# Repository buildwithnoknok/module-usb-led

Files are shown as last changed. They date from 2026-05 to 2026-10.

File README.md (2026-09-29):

# noknok LEDs

A USB-controlled ring of 8 WS2812b RGB LEDs for the noknok ecosystem. The Raspberry Pi
Pico drives it as a **USB host**; it can also be driven directly from a PC.

## Features
- 8× WS2812b RGB LEDs (ring)
- CH32V203G6U6 microcontroller, USB 1.1 (CDC) device
- USB-C power + data; 2× Qwiic / STEMMA QT compatible I2C pass-through connectors
- **Unique per-unit USB serial** derived from the chip UID — so the Conductor can tell
  identical modules apart and map them to roles (the USB counterpart of the I2C UID)
- Rich control: per-LED colour/brightness/timed-off in one command, plus 6 built-in
  animations (rainbow, breathe, theatre chase, colour wipe, twinkle, sundown)

## Status
- **Firmware: v1.8.2 — complete** (see [firmware/readme.md](firmware/readme.md) for the
  full command protocol, flashing instructions, and version history)
- Hardware: v1.0

## How it's controlled

### From a Raspberry Pi Pico (USB host) — the noknok Conductor
The Pico hosts the module over PIO-USB (D+ → GP16, D− → GP17, behind a **powered** hub
such as the DataHub). The `NoknokLEDs` driver lives in
[`brain-Pico/software/noknok_usb.py`](https://github.com/buildwithnoknok/brain-Pico/tree/main/software)
and is discovered by the Conductor:

```python
from noknok import Conductor

c = Conductor()
c.enumerate_usb()          # brings up the USB host port, finds all LED modules
# (use c.enumerate_all() for a product that mixes I2C + USB modules)

leds = c.leds[0]                                  # or c.by_uid("<serial>"), or c.role["lamp"]
leds.set_all(255, 0, 0)                           # all red
leds.set_pixel(3, 0, 255, 0)                      # LED 3 green
leds.set_brightness(128)                          # global brightness
leds.set_led(0xFF, 0, 0, 255, brightness=200, duration_ms=1000)  # all blue 1 s, then off
leds.play_preset(leds.PRESET_RAINBOW, speed=40)  # non-blocking animation on the module
leds.play_preset(leds.PRESET_SUNDOWN, speed=30, r=0, g=0, b=255)  # 30 min fade to off, blue
leds.off()
```

Each module carries a unique serial, so multiple LED modules on one hub are addressed
individually. See **[Ecosystem → enumeration.md](https://github.com/buildwithnoknok/Ecosystem/blob/main/software/enumeration.md)**
(USB Module Discovery & Identity) and **[roles.md](https://github.com/buildwithnoknok/Ecosystem/blob/main/software/roles.md)**
(role assignment — this is an *output* module, assigned by cue-and-confirm).

### From a PC
PowerShell / Python helpers in [`tools/`](tools) (`noknok_leds.ps1`, `noknok_leds_pc.py`)
auto-detect the module and expose the same commands.

## Repository Structure
- `/hardware` — KiCad files, schematics, 3D models
- `/firmware` — source (`src/`), built binaries (`bin/`), and the firmware change record (`readme.md`)
- `/tools` — PC control scripts

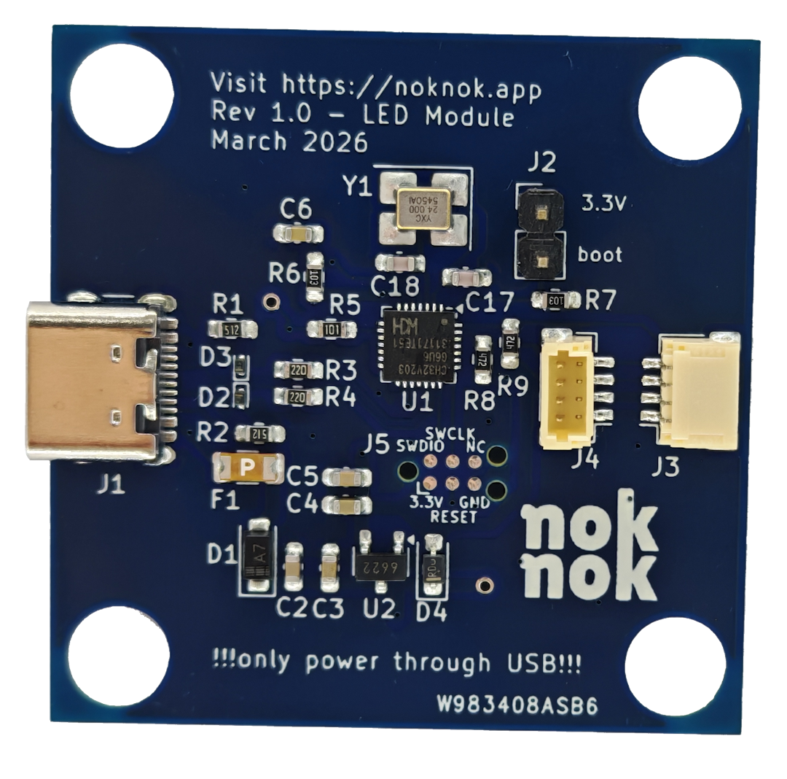
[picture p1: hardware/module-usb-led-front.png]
USB LED Module

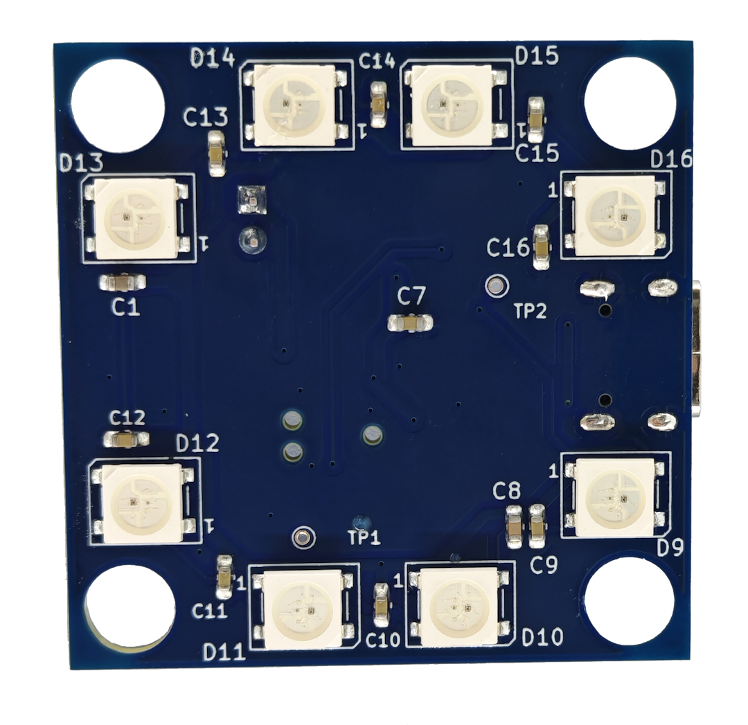
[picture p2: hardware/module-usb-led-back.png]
USB LED Module


---

## Trademarks

**noknok** is a registered trademark in Switzerland (Swissreg 1300007033).

Qwiic is a registered trademark of SparkFun Electronics, Inc. STEMMA QT is a
trademark of Adafruit Industries, LLC. Both are named here only to state
connector compatibility - noknok is not affiliated with, endorsed by, or
sponsored by either company.

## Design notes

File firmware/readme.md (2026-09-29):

# Firmware — noknok LEDs

Firmware for the noknok LEDs module (CH32V203G6U6 — USB, 8× WS2812b RGB).

- Source: `src/` (built with [ch32fun](https://github.com/cnlohr/ch32fun); `Makefile` uses `extralibs/usbd.c`)
- Binaries: `bin/noknok_leds.bin` and `bin/noknok_leds.hex` — current release
- USB identity: VID `0x1209` / PID `0x4E4E` (app) / PID `0x4E42` (bootloader). Appears as a CDC serial device ("noknok LEDs"). Each unit has a **unique serial number** derived from its chip UID (v1.6+).

Firmware is licensed MIT (see `../LICENSE-firmware`). Toolchain and protocol follow the
[noknok Ecosystem guidelines](https://github.com/buildwithnoknok/Ecosystem).

## Flashing (USB bootloader — no programmer needed)
1. Fit the **BOOT0 jumper**, plug into USB-C, power-cycle → the chip enters the WCH USB bootloader.
2. In **WCHISPTool**: select chip **CH32V203 (G6U6)**, load **`bin/noknok_leds.bin`**, click Download. Leave "Enable RRP" **unchecked**.
3. Remove the BOOT0 jumper and power-cycle.

A brief **dim-white boot flash (~0.3 s)** means the firmware is running; a **"noknok LEDs" COM port** then appears.
A *constant* solid-white means the firmware is **not** running (old/failed flash or bootloader mode) — re-flash.

> You can also flash `bin/noknok_leds.hex` the same way, or via SWD with a WCH-Link-E (`make flash`).

## Controlling the module
- From a PC: PowerShell / Python helpers in [`../tools/`](../tools) (`noknok_leds.ps1`, `noknok_leds_pc.py`).
- From a Raspberry Pi Pico (USB host): the `NoknokLEDs` class in the brain-Pico `noknok.py` (`usb.core`, raw bulk to EP `0x02`).

**Command protocol** (raw bytes, host → module):

| Bytes | Action |
|---|---|
| `0x00` | all LEDs off |
| `0x01 R G B` | set all 8 LEDs |
| `0x02 i R G B` | set LED `i` (0–7) |
| `0x03 B` | global brightness 0–255 |
| `0x04 [24 bytes]` | set all 8 LEDs: 8 × (R G B) |
| `0x05` | explicit show |
| `0x10 i R G B BR dLo dHi` | **SET_LED** — LED `i` (`0xFF` = all), colour, brightness, duration ms little-endian (0 = hold) |
| `0x20 preset speed R G B` | **PLAY_PRESET** 1–6 (rainbow / breathe / theatre-chase / colour-wipe / twinkle / **sundown**); `speed` = ms per step (0 = default) — **EXCEPT preset 6 (sundown), where `speed` means MINUTES instead (0 = default 30)**; `R G B` = base colour |
| `0xF0` | identity query → module replies `0x4E 0x4E 0x04` |
| `0xB1` | version query → replies `[PROTOCOL, MAJOR, MINOR, PATCH]` |

---

## Firmware Change Record

### v1.8.2 — lossless USB receive (current) — released 2026-09-29
- **Bug fix: commands could be lost or misread when sent back-to-back.** ch32fun `usbd.c`'s
  printf receive path (`FUNCONF_USE_USBPRINTF`) keeps a 64-byte buffer and throws away the
  OLDEST bytes when another USB packet arrives before the main loop has read it. The parser
  then desynced and leftover colour bytes ran as commands — a `0x00` byte means "all off",
  so the ring could go dark or show wrong colours. Found on the LEDs 16x bench.
- **Fix:** `FUNCONF_USE_USBPRINTF 0` (+ `FUNCONF_NULL_PRINTF 1`); the firmware implements the
  CDC callbacks itself with a 256-byte ring filled in the USB interrupt. When less than one
  packet (64 B) of room is left the USB interrupt is masked, so the endpoint answers NAK and
  the host simply retries — true flow control, no byte can be dropped. The main loop drains
  the ring, unmasks, then parses.
- Test: `tools/stress_leds8.py` (hundreds of back-to-back `0x04` frames, then compare the ring
  with the printed expected frame).
- No protocol or behaviour change otherwise. Flash 6360 B (26 %), RAM 1256 B.

### v1.8.1 — sundown preset — released 2026-07-02
- **New preset 6 = SUNDOWN.** `0x20 6 minutes R G B` plays a **one-shot** fade from full
  brightness to off in the caller-supplied colour, over `minutes` minutes (not the usual
  `speed`-as-ms/step — see below). Unlike presets 1–5, which loop forever until the next
  command, SUNDOWN runs once and stops itself (LEDs off) at the end instead of repeating.
  Intended for a bedtime/wind-down light (e.g. blue, 30 min).
- **Easing is CONCAVE (quadratic ease-out), not linear:** brightness follows
  `(1 - elapsed/total)²`, so it dims fast at the start and slows to a crawl near the end
  (e.g. at the halfway point in time, brightness is at 25%, not 50%). Computed in Q10
  fixed-point integer math — no FPU on this MCU, same approach as the rest of the firmware.
- **`speed` field is repurposed for this preset only:** every other preset's `speed` byte
  means "ms per animation step", which can't encode a useful multi-minute total duration in
  one byte. For preset 6 only, `speed` means **minutes** (1–255; 0 defaults to 30). This is a
  deliberate, documented exception — not a silent redefinition of the field ecosystem-wide.
- Flash usage 6328 B (26% of 24 KB app region), RAM 1060 B. No other behavioural changes
  from v1.8.0 (see v1.8.0 below for the OTA/bootloader-hosted architecture change).

### v1.8.0 — OTA-capable, bootloader-hosted — released 2026-06-23
- App relinked at `0x2000` (`app.ld`) to run under the noknok USB bootloader
  (`module-USB-bootloader`), with the top 16 B of RAM reserved as the handoff cell.
- `0xB0` ENTER_BOOTLOADER: writes the handoff magic + resets; the bootloader catches it and
  stays in USB flashing mode. Updates now flash over USB via `usb_flash.ps1` / the Pico's
  `UsbModuleFlasher` — no BOOT0 jumper needed after the bootloader's one-time flash.

### v1.6 — unique serial + rich LED control & presets — released 2026-06-18
- **Unique USB serial number.** `iSerialNumber` is now built at boot from the CH32V203's 96-bit hardware chip UID (ESIG at `0x1FFFF7E8`) as 24 hex characters, so every physical module enumerates with a **distinct serial**. This is the USB counterpart of the I2C hardware UID — it lets the Conductor tell identical modules apart and map them to roles. (Previously all modules shared the hardcoded serial `"007"`.)
- **`0x10` SET_LED — full per-LED control in one command:** `0x10 i R G B brightness durLo durHi`. `i` = LED index (`0xFF` = all); `duration` is 16-bit ms (little-endian; `0` = hold indefinitely, otherwise the LED(s) auto-off after the duration). Non-blocking.
- **`0x20` PLAY_PRESET — 5 built-in non-blocking animations** that run on the module (fire-and-forget, mirroring the buzzer's preset tunes): `1` rainbow rotate, `2` breathe, `3` theatre chase, `4` colour wipe, `5` twinkle. `0x20 preset speed R G B` — `speed` = ms per animation step (`0` = default 40 ms); `R G B` = base colour (ignored by rainbow). Any immediate command (`0x00`–`0x05`, `0x10`) cancels a running animation.
- Added a **TIM3 free-running 1 ms timebase** for durations and animation stepping.
- Flash usage 6052 B (18% of 32 KB), RAM 1056 B.

### v1.5 — adds firmware version query — released 2026-06-17
- **`0xB1` GET_VERSION command** (noknok ecosystem standard, command range 0xB0–0xBF). The module replies with 4 bytes: `[PROTOCOL_VERSION, FW_MAJOR, FW_MINOR, FW_PATCH]` = `0x01, 1, 5, 0`. Lets the host (Pico or PC) read which firmware a module is running — needed by the OTA update flow. Matches the I2C modules' `0xB1` convention.
- No other behavioural changes from v1.4.

### v1.4 — first working release — released 2026-06-04
- **USB stack switched from USBFS (fsusb) to USBD (FSDEV).** On this board the USBFS controller's D+ pull-up is not host-visible, so it never enumerated; the USBD/FSDEV controller (pull-up via `EXTEN_USBD_PU_EN`, the same path the WCH bootloader uses) enumerates reliably as a USB CDC device.
- **Manual clock bring-up: HSE 24 MHz × 2 = 48 MHz** (crystal-accurate 48 MHz USB clock). ch32fun's automatic CH32V203 clock setup does not work for this part (no flash wait-states above 24 MHz; it disables HSI mid-switch), so the firmware boots on the internal HSI and switches to the crystal + PLL itself.
- **Behaviour:** dim-white boot flash on power-up, then enumerates as "noknok LEDs" (VID `0x1209` / PID `0x4E4E`). LED commands are sent as raw bytes over the CDC data endpoint.
- Driveable from a PC (`../tools/`) or from a Pico acting as USB host (`usb.core`).

### v1.0 – v1.3 — bring-up (superseded, non-functional)
- Early builds used the USBFS (fsusb) stack and ch32fun's default 144 MHz clock. They did not run / did not enumerate due to the CH32V203 clock issues described under v1.4. Superseded.

### Abandoned experiment — full CDC line-coding (not released, no version assigned)
- An attempt (between v1.4 and v1.5) to add full CDC line-coding so standard host serial APIs (e.g. .NET `SerialPort.Open`) could open the port. Caused Windows "Code 10 — device cannot start"; root cause not isolated, so it was dropped. (PC tools instead open the port via a raw handle / pyserial, which works.)

## Known limitations
- The minimal CDC implementation does not fully answer line-coding requests, so .NET `SerialPort.Open()` is fussy. Use the provided PowerShell/Python tools (raw handle / pyserial), or `usb.core` raw bulk on the Pico.
- USB VID/PID are pid.codes **prototype** values (`0x1209` / `0x4E4E`) — assign production IDs before release.

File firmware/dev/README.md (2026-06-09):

# ch32fun dev patches (CH32V203)

Optional patches to cnlohr/ch32fun `ch32fun.c` that fix the automatic clock setup
for CH32V203 (flash wait-states at >24 MHz; HSE-enable preserving the active HSI).

NOT required by the shipped LED firmware (noknok_leds.c does its own manual HSE/PLL
bring-up). Kept for reference if anyone wants ch32fun's auto-clock to work on V203.
See the LED debug history in the Sam agent notes for full context.

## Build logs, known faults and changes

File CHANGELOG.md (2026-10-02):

# Changelog - noknok LEDs (8x) module firmware

Newest first. One entry per version bump, written in the same commit as the bump. Format:
`## <version> - <date>` then `- DEV-xx - what changed and why. Breaking: yes/no.`
Convention: Confluence "Development Conventions" (SD space, page 120160257).

## Baseline - 2026-10-02

- Changelog starts here. Current: usb_leds firmware 1.8.2 (released 2026-09-29). Earlier history: git log and the README.

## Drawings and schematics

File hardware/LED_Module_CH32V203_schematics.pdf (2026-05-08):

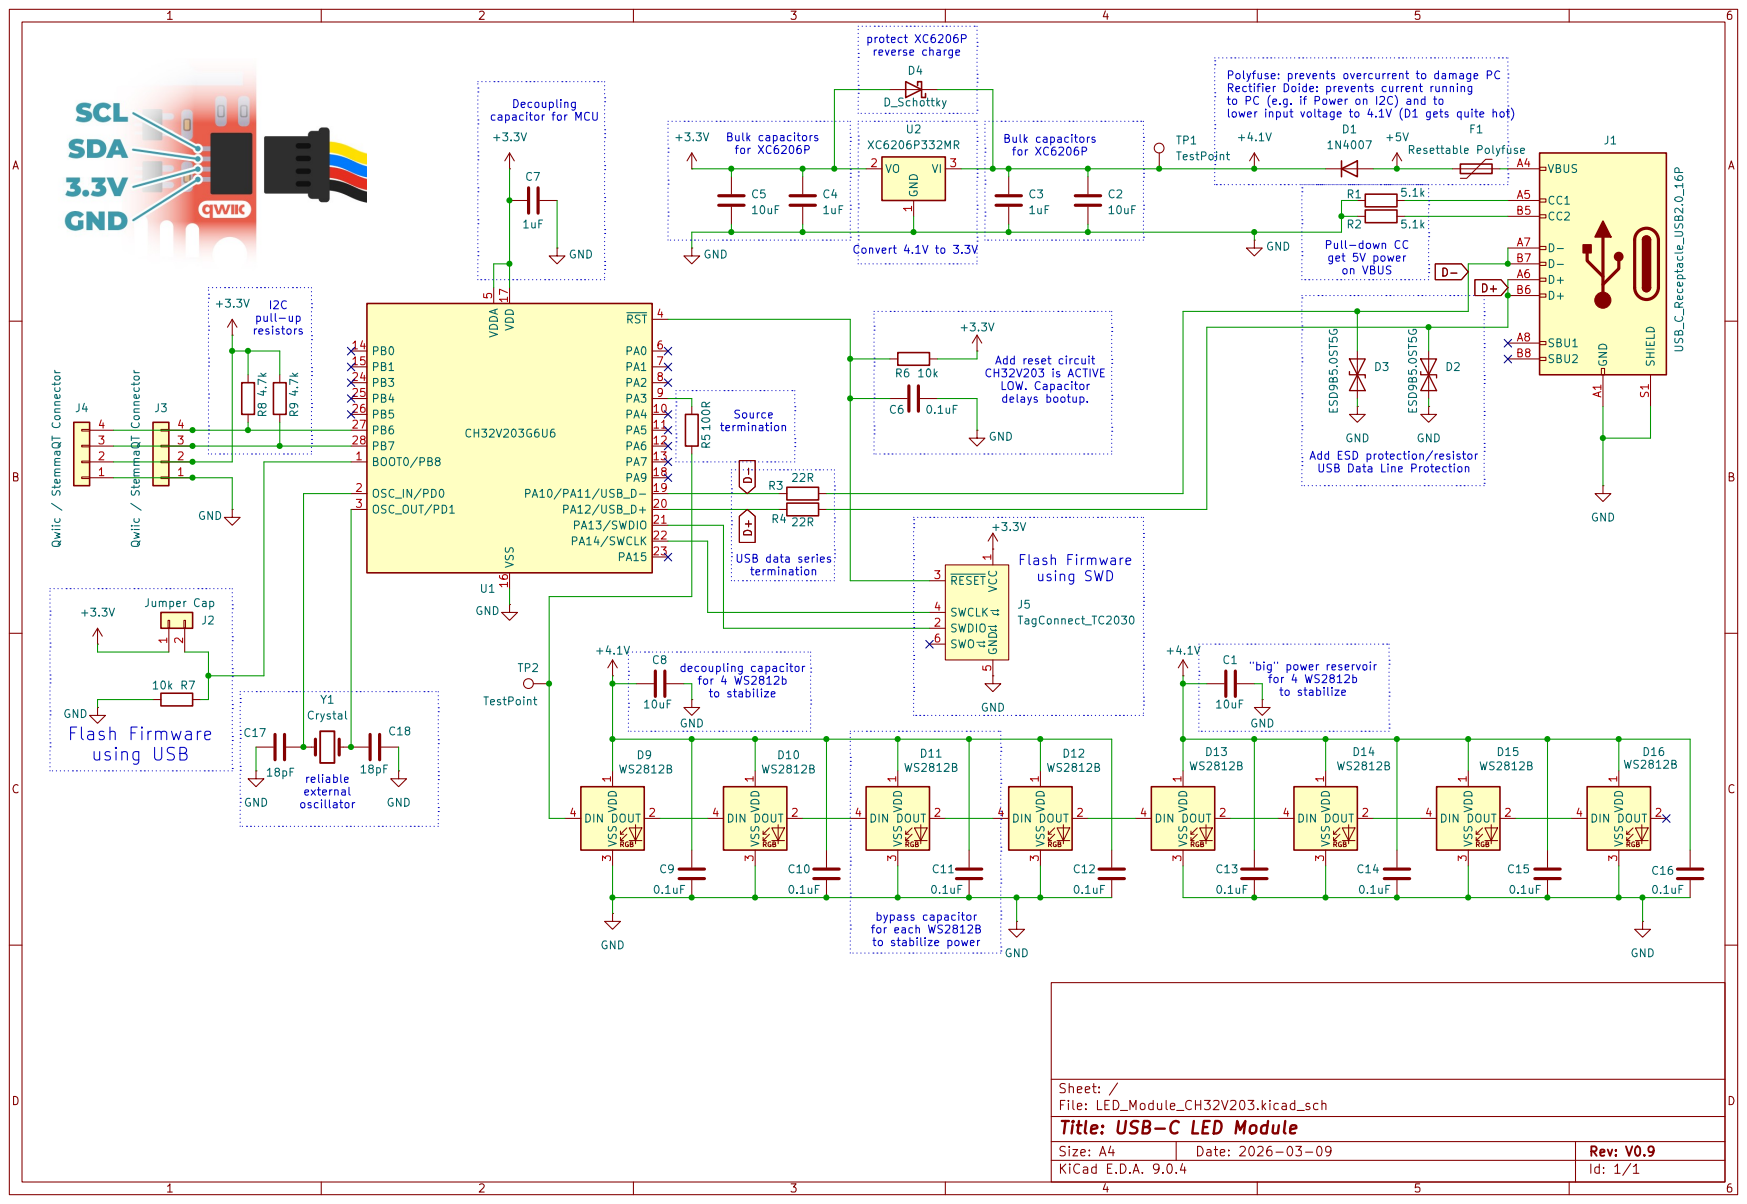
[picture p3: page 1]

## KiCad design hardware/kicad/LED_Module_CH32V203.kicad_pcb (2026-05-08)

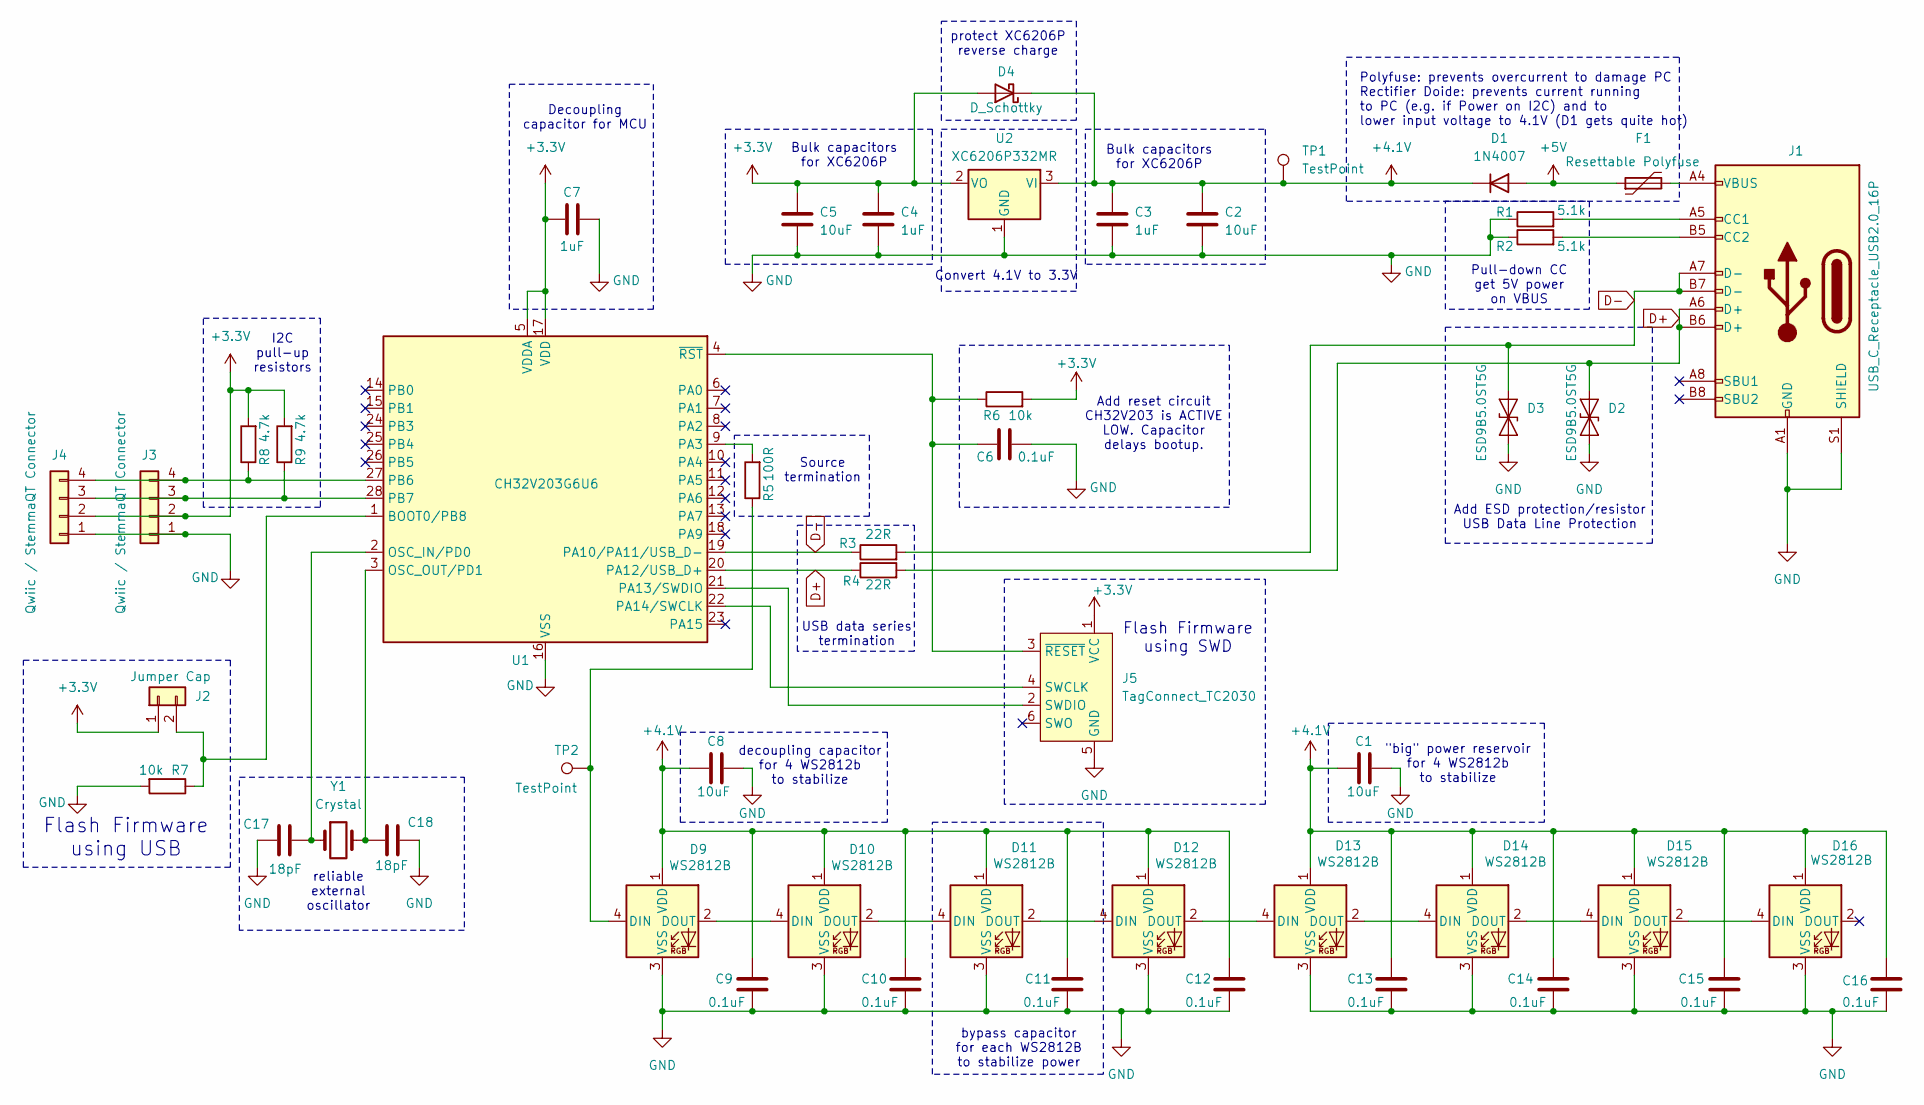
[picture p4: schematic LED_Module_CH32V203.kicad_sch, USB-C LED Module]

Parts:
C1, C2, C5, C8: 10uF; C_0603_1608Metric_Pad1.08x0.95mm_HandSolder
C3, C4, C7: 1uF; C_0603_1608Metric_Pad1.08x0.95mm_HandSolder
C6, C9, C10, C11, C12, C13, C14, C15, C16: 0.1uF; C_0603_1608Metric_Pad1.08x0.95mm_HandSolder
C17, C18: 18pF; C_0603_1608Metric_Pad1.08x0.95mm_HandSolder
D1: 1N4007; D_SOD-123
D2, D3: ESD9B5.0ST5G; D_SOD-923
D4: D_Schottky; D_SOD-323_HandSoldering
D9, D10, D11, D12, D13, D14, D15, D16: WS2812B; LED_WS2812B_PLCC4_5.0x5.0mm_P3.2mm
F1: Resettable Polyfuse; Fuse_1206_3216Metric
J1: USB_C_Receptacle_USB2.0_16P; USB_C_Receptacle_GCT_USB4105-xx-A_16P_TopMnt_Horizontal
J2: Jumper Cap; PinHeader_1x02_P2.54mm_Vertical
J3: Qwiic / StemmaQT Connector; JST_SH_SM04B-SRSS-TB_1x04-1MP_P1.00mm_Horizontal_CHRIS
J4: Qwiic / StemmaQT Connector; JST_SH_BM04B-SRSS-TB_1x04-1MP_P1.00mm_Vertical
J5: TagConnect_TC2030; Tag-Connect_TC2030-IDC-NL_2x03_P1.27mm_Vertical
R1, R2: 5.1k; R_0603_1608Metric_Pad0.98x0.95mm_HandSolder
R3, R4: 22R; R_0603_1608Metric_Pad0.98x0.95mm_HandSolder
R5: 100R; R_0603_1608Metric_Pad0.98x0.95mm_HandSolder
R6, R7: 10k; R_0603_1608Metric_Pad0.98x0.95mm_HandSolder
R8, R9: 4.7k; R_0603_1608Metric_Pad0.98x0.95mm_HandSolder
TP1, TP2: TestPoint; TestPoint_THTPad_D1.0mm_Drill0.5mm
U1: CH32V203G6U6; WQFN-28-1EP_4x4mm_P0.4mm_EP2.7x2.7mm
U2: XC6206P332MR; SOT-23-3
Y1: Crystal; Crystal_SMD_3225-4Pin_3.2x2.5mm_HandSoldering

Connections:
+3.3V: C4.1, C5.1, C7.1, D4.2 (A), J2.1, J3.2, J4.2, J5.1 (VCC), R6.2, R8.2, R9.2, U1.5 (VDDA), U1.17 (VDD), U2.2 (VO)
+4.1V: C1.1, C2.1, C3.1, C8.1, C9.1, C10.1, C11.1, C12.1, C13.1, C14.1, C15.1, C16.1, D1.1 (K), D4.1 (K), D9.1 (VDD), D10.1 (VDD), D11.1 (VDD), D12.1 (VDD), D13.1 (VDD), D14.1 (VDD), D15.1 (VDD), D16.1 (VDD), TP1.1, U2.3 (VI)
+5V: D1.2 (A), F1.1
D+: D2.1 (A1), J1.A6 (D+), J1.B6 (D+), R4.1, R4.2, U1.20 (PA12/USB_D+)
D-: D3.1 (A1), J1.A7 (D-), J1.B7 (D-), R3.1, R3.2, U1.19 (PA10/PA11/USB_D-)
GND: C1.2, C2.2, C3.2, C4.2, C5.2, C6.1, C7.2, C8.2, C9.2, C10.2, C11.2, C12.2, C13.2, C14.2, C15.2, C16.2, C17.1, C18.1, D2.2 (A2), D3.2 (A2), D9.3 (VSS), D10.3 (VSS), D11.3 (VSS), D12.3 (VSS), D13.3 (VSS), D14.3 (VSS), D15.3 (VSS), D16.3 (VSS), J1.A1 (GND), J1.A12 (GND), J1.B1 (GND), J1.B12 (GND), J1.S1 (SHIELD), J3.1, J4.1, J5.5 (GND), R1.1, R2.1, R7.2, U1.16 (VSS), U1.29 (VSS), U2.1 (GND)
unnamed: D9.4 (DIN), R5.1, TP2.1
unnamed: D9.2 (DOUT), D10.4 (DIN)
unnamed: D10.2 (DOUT), D11.4 (DIN)
unnamed: D11.2 (DOUT), D12.4 (DIN)
unnamed: D12.2 (DOUT), D13.4 (DIN)
unnamed: D13.2 (DOUT), D14.4 (DIN)
unnamed: D14.2 (DOUT), D15.4 (DIN)
unnamed: D15.2 (DOUT), D16.4 (DIN)
unnamed: F1.2, J1.A4 (VBUS), J1.A9 (VBUS), J1.B4 (VBUS), J1.B9 (VBUS)
unnamed: J1.A5 (CC1), R1.2
unnamed: J1.B5 (CC2), R2.2
unnamed: J2.2, R7.1, U1.1 (BOOT0/PB8)
unnamed: J3.3, J4.3, R9.1, U1.28 (PB7)
unnamed: J3.4, J4.4, R8.1, U1.27 (PB6)
unnamed: J5.4 (SWCLK), U1.22 (PA14/SWCLK)
unnamed: J5.2 (SWDIO), U1.21 (PA13/SWDIO)
unnamed: C6.2, J5.3 (~RESET), R6.1, U1.4 (~RST)
unnamed: C17.2, U1.2 (OSC_IN/PD0), Y1.1
unnamed: C18.2, U1.3 (OSC_OUT/PD1), Y1.2
unnamed: R5.2, U1.9 (PA3)

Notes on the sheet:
decoupling capacitor for 4 WS2812b to stabilize
Polyfuse: prevents overcurrent to damage PC Rectifier Doide: prevents current running to PC (e.g. if Power on I2C) and to lower input voltage to 4.1V (D1 gets quite hot)
Pull-down CC get 5V power on VBUS
Source termination
Add reset circuit CH32V203 is ACTIVE LOW. Capacitor delays bootup.
USB data series termination
Decoupling capacitor for MCU
reliable external oscillator
Flash Firmware using USB
Flash Firmware using SWD
"big" power reservoir for 4 WS2812b to stabilize
Bulk capacitors for XC6206P
Add ESD protection/resistor USB Data Line Protection
Convert 4.1V to 3.3V
protect XC6206P reverse charge
bypass capacitor for each WS2812B to stabilize power
I2C pull-up resistors

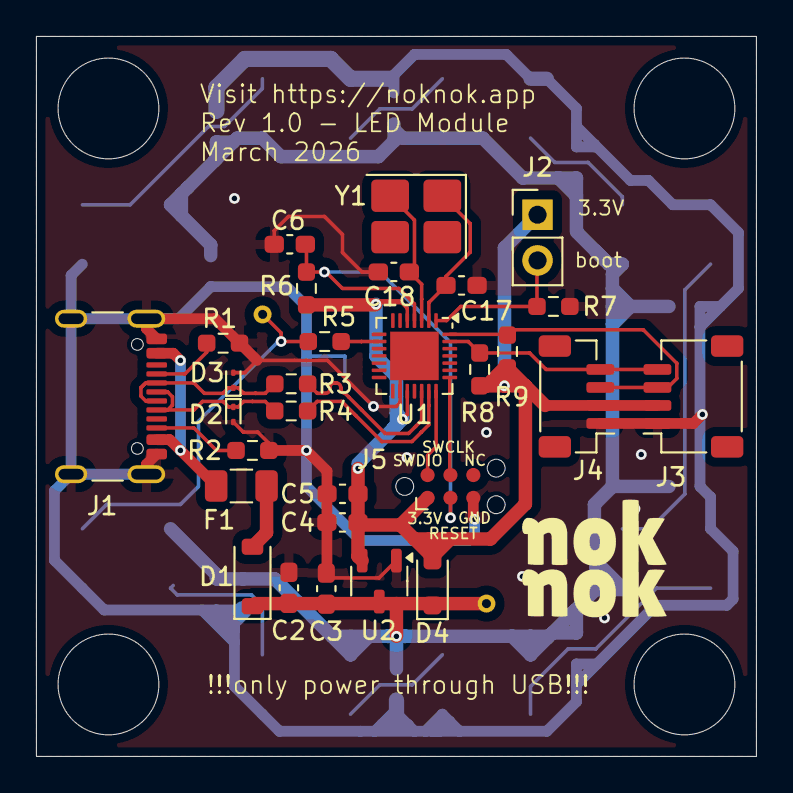
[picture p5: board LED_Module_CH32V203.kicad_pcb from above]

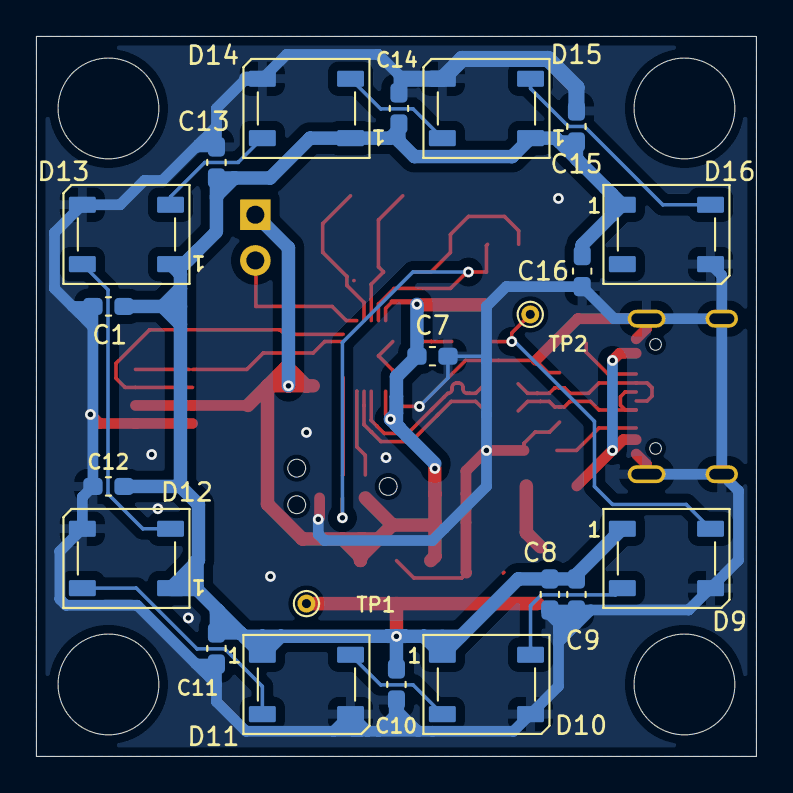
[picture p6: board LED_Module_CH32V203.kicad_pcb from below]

Board: 2 copper layers, 40.0 x 40.0 mm, 50 parts (21 on the bottom side), 26 nets.

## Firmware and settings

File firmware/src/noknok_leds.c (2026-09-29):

/*
 * noknok LEDs Module - Firmware v1.8.2 (USBD / FSDEV)
 * MCU:   CH32V203G6U6
 * CLOCK: boots on HSI, manual switch to HSE(24MHz) x2 = 48 MHz (crystal-accurate).
 * USB:   USBD (FSDEV) controller via extralibs/usbd.c - the SAME controller the
 *        WCH bootloader uses (D+ pull-up via EXTEN_USBD_PU_EN).
 *        48 MHz core -> USBPRE=DIV1 -> 48 MHz USB clock.
 * LEDs:  8x WS2812b on PA3 via TIM2_CH4 + DMA1_Channel2 (polling).
 * TIME:  TIM3 free-running 1 kHz (1 ms/tick) timebase for durations + animations.
 *
 * v1.6 changes:
 *   - UNIQUE USB SERIAL: iSerialNumber is built at boot from the 96-bit chip UID
 *     (ESIG at 0x1FFFF7E8) -> 24 hex chars, so every module is uniquely
 *     identifiable on the USB bus (USB counterpart of the I2C UID).
 *   - 0x10 SET_LED: full per-LED control in one command (index/RGB/brightness/duration).
 *   - 0x20 PLAY_PRESET: 5 non-blocking animations (rainbow/breathe/chase/wipe/twinkle),
 *     fire-and-forget on the module (mirrors the buzzer's preset tunes).
 *
 * Command protocol (binary over USB serial; see module README):
 *   0x00                              all off
 *   0x01 R G B                        all one colour
 *   0x02 i R G B                      one LED
 *   0x03 B                            global brightness
 *   0x04 [24]                         8x RGB at once
 *   0x05                              show (re-latch current frame)
 *   0x10 i R G B BR durLo durHi       SET_LED: i(0xFF=all), brightness, duration ms (0=hold)
 *   0x20 preset speed R G B           PLAY_PRESET 1..6 (speed=ms/step, 0=default -
 *                                     EXCEPT preset 6 SUNDOWN, where speed instead
 *                                     means MINUTES, 0=default 30 - see below)
 *   0xF0  -> 4E 4E 04                 identity
 *   0xB1  -> PROTO MAJ MIN PAT        GET_VERSION
 *   0xB0  -> (no reply)               ENTER_BOOTLOADER: hand off to the noknok USB bootloader (OTA)
 *
 * v1.8 changes (OTA-capable, bootloader-hosted):
 *   - App relinked at 0x2000 (app.ld) to run UNDER the noknok USB bootloader
 *     (module-USB-bootloader), with the top 16 B of RAM reserved as the handoff cell.
 *   - 0xB0 ENTER_BOOTLOADER: writes the handoff magic (0x6E6B4F54 @ 0x200027F0) +
 *     NVIC_SystemReset(); the bootloader catches it on reset and stays in USB
 *     flashing mode. Same proven pattern as the I2C modules.
 *   - Requires the bootloader flashed once via the BOOT0 jumper; thereafter the
 *     app updates over USB (tools/usb_flash.ps1 in module-USB-bootloader).
 *
 * v1.8.1 changes:
 *   - NEW PRESET 6 = SUNDOWN: a ONE-SHOT fade from full brightness to off in the
 *     caller-supplied colour (e.g. blue, for a "help my kid fall asleep" light).
 *     Unlike presets 1-5 (which loop forever until the next command), SUNDOWN
 *     runs once and then stops itself (anim=0) with the LEDs off.
 *   - EASING: quadratic ease-out, fraction = (1 - t/total)^2, computed in Q10
 *     fixed point (no FPU on this MCU). This is CONCAVE: brightness drops fast
 *     at the start and crawls the last stretch down to zero, not a linear ramp.
 *   - SPEED FIELD REPURPOSED FOR THIS PRESET ONLY: the existing `speed` byte in
 *     0x20 PLAY_PRESET means "ms per animation step" for presets 1-5, but a
 *     single byte of milliseconds cannot encode a useful total duration for a
 *     multi-minute fade. For preset 6 ONLY, `speed` is reinterpreted as MINUTES
 *     (1-255 min); 0 defaults to 30 min. This is a deliberate, flagged exception
 *     -- not a silent redefinition -- so a future preset must NOT assume `speed`
 *     always means ms/step without checking which preset it's serving.
 *
 * v1.8.2 changes (29 Sep 2026):
 *   - LOSSLESS USB RECEIVE. usbd.c's printf RX path (64 B buffer, discard-oldest)
 *     could drop bytes when more than one packet arrived before the main loop polled;
 *     the parser then desynced and stray 0x00 bytes executed as ALL OFF. Now our own
 *     256 B ring + USB NAK flow control (see 'USB receive path').
 *     FUNCONF_USE_USBPRINTF = 0. Same fix as the LEDs 16x firmware v2.0.1.
 */

#include "ch32fun.h"
#include "usbd.h"
#include <string.h>

/* Firmware version - reported via 0xB1 GET_VERSION (noknok ecosystem standard,
 * command range 0xB0-0xBF). PROTOCOL_VERSION = shared noknok protocol level;
 * FW_VERSION_* = this firmware's semver (keep equal to the release tag). */
#define PROTOCOL_VERSION  0x01
#define FW_VERSION_MAJOR  1
#define FW_VERSION_MINOR  8
#define FW_VERSION_PATCH  2

/* ============================================================
 * Unique USB serial number (built from chip UID at boot)
 * Raw USB string descriptor: [bLength=50, bDescriptorType=3, 24x UTF-16LE hex].
 * usb_config.h references this via `extern uint8_t noknok_serial[]`.
 * ============================================================ */
uint8_t noknok_serial[2 + 24 * 2];

static void build_serial(void) {
    const volatile uint8_t *uid = (const volatile uint8_t *)0x1FFFF7E8; /* ESIG UNIID, 96-bit */
    static const char H[] = "0123456789ABCDEF";
    noknok_serial[0] = sizeof(noknok_serial);  /* bLength = 50 */
    noknok_serial[1] = 0x03;                    /* bDescriptorType = String */
    for (int i = 0; i < 12; i++) {              /* 12 UID bytes -> 24 hex chars */
        uint8_t b = uid[i];
        uint8_t hi = H[b >> 4], lo = H[b & 0x0F];
        noknok_serial[2 + (i * 2) * 2]     = hi;  noknok_serial[2 + (i * 2) * 2 + 1]     = 0x00;
        noknok_serial[2 + (i * 2 + 1) * 2] = lo;  noknok_serial[2 + (i * 2 + 1) * 2 + 1] = 0x00;
    }
}

/* ============================================================
 * Manual clock: HSI boot -> HSE 24 MHz x2 = 48 MHz
 * ============================================================ */
static int clock_to_hse_48(void) {
    RCC->CTLR |= RCC_HSEON;
    volatile uint32_t t = 1500000;
    while (t--) { if (RCC->CTLR & RCC_HSERDY) break; }
    if (!(RCC->CTLR & RCC_HSERDY)) return 0;
    FLASH->ACTLR = (FLASH->ACTLR & ~0x07u) | 0x01u;       /* 1 wait-state @48MHz */
    RCC->CFGR0 = RCC_HPRE_DIV1 | RCC_PPRE1_DIV1 | RCC_PPRE2_DIV1
               | RCC_PLLSRC | RCC_PLLMULL2;
    RCC->CTLR |= RCC_PLLON;
    t = 1500000;
    while (t--) { if (RCC->CTLR & RCC_PLLRDY) break; }
    if (!(RCC->CTLR & RCC_PLLRDY)) return 0;
    RCC->CFGR0 = (RCC->CFGR0 & ~(uint32_t)0x03) | RCC_SW_PLL;
    t = 1500000;
    while (t--) { if ((RCC->CFGR0 & RCC_SWS) == 0x08) break; }
    return ((RCC->CFGR0 & RCC_SWS) == 0x08);
}

/* ============================================================
 * TIM3 free-running 1 ms timebase
 * ============================================================ */
static void timebase_init(void) {
    RCC->APB1PCENR |= RCC_APB1Periph_TIM3;
    TIM3->PSC    = 48000 - 1;     /* 48 MHz / 48000 = 1 kHz -> 1 tick per ms */
    TIM3->ATRLR  = 0xFFFF;
    TIM3->CTLR1  = TIM_ARPE;
    TIM3->SWEVGR = TIM_UG;
    TIM3->CTLR1 |= TIM_CEN;
}
static inline uint16_t now_ms(void) { return (uint16_t)TIM3->CNT; }

/* ============================================================
 * WS2812b driver (polling) @48MHz
 * ============================================================ */
#define LED_COUNT      8
#define WS_PERIOD      60
#define WS_T1H         38
#define WS_T0H         19
#define WS_RESET_BITS  60
#define WS_BUF_LEN     (LED_COUNT * 24 + WS_RESET_BITS)

static uint16_t ws_dma_buf[WS_BUF_LEN] __attribute__((aligned(4)));

static void ws_build_buf(uint8_t *grb) {
    uint16_t *p = ws_dma_buf;
    for (int i = 0; i < LED_COUNT * 3; i++) {
        uint8_t byte = grb[i];
        for (int bit = 7; bit >= 0; bit--)
            *p++ = (byte >> bit) & 1 ? WS_T1H : WS_T0H;
    }
    memset(p, 0, WS_RESET_BITS * sizeof(uint16_t));
}

static void ws_init(void) {
    RCC->APB1PCENR |= RCC_APB1Periph_TIM2;
    RCC->AHBPCENR  |= RCC_AHBPeriph_DMA1;     /* re-enable DMA1 (USBDSetup overwrote AHBPCENR) */
    RCC->APB2PCENR |= RCC_APB2Periph_AFIO | RCC_APB2Periph_GPIOA;
    GPIOA->CFGLR = (GPIOA->CFGLR & ~(0xFUL << 12)) | (0xBUL << 12);
    TIM2->PSC     = 0;
    TIM2->ATRLR   = WS_PERIOD - 1;
    TIM2->CH4CVR  = 0;
    TIM2->CHCTLR2 = (TIM2->CHCTLR2 & ~0xFF00) | (0x60 << 8);
    TIM2->CCER   |= TIM_CC4E;
    TIM2->CTLR1  |= TIM_ARPE;
    TIM2->DMAINTENR |= TIM_UDE;
    DMA1_Channel2->CFGR  = 0;
    DMA1_Channel2->PADDR = (uint32_t)&TIM2->CH4CVR;
    DMA1_Channel2->CFGR  =
        DMA_CFGR1_DIR | DMA_CFGR1_MINC | DMA_CFGR1_PSIZE_0 |
        DMA_CFGR1_MSIZE_0 | DMA_CFGR1_PL_1;
    TIM2->CTLR1 |= TIM_CEN;
}

static void ws_show(uint8_t *grb) {
    ws_build_buf(grb);
    DMA1_Channel2->CFGR  &= ~DMA_CFGR1_EN;
    DMA1->INTFCR = DMA1_IT_TC2;
    DMA1_Channel2->CNTR  = WS_BUF_LEN;
    DMA1_Channel2->MADDR = (uint32_t)ws_dma_buf;
    DMA1_Channel2->CFGR |= DMA_CFGR1_EN;
    TIM2->SWEVGR = TIM_UG;
    while (!(DMA1->INTFR & DMA1_IT_TC2));
    DMA1->INTFCR = DMA1_IT_TC2;
}

/* ============================================================
 * LED state
 * ============================================================ */
static uint8_t fr[LED_COUNT], fg[LED_COUNT], fb[LED_COUNT];
static uint8_t brightness = 255;
static inline uint8_t scale(uint8_t v) { return (uint16_t)v * brightness / 255; }

static void show(void) {
    uint8_t grb[LED_COUNT * 3];
    for (int i = 0; i < LED_COUNT; i++) {
        grb[i*3+0] = scale(fg[i]); grb[i*3+1] = scale(fr[i]); grb[i*3+2] = scale(fb[i]);
    }
    ws_show(grb);
}
static void set_all(uint8_t r, uint8_t g, uint8_t b) {
    for (int i = 0; i < LED_COUNT; i++) { fr[i]=r; fg[i]=g; fb[i]=b; }
}

/* ============================================================
 * Per-LED timed-off (0x10 duration) + animation engine (0x20)
 * ============================================================ */
static uint16_t led_deadline[LED_COUNT];   /* TIM3 ms value at which the LED turns off */
static uint8_t  led_timed[LED_COUNT];      /* 1 = a deadline is armed for this LED */

static uint8_t  anim = 0;                   /* 0 = none, 1..6 = active preset */
static uint8_t  anim_r, anim_g, anim_b;     /* preset base colour */
static uint16_t anim_step_ms = 40;          /* ms between animation steps */
static uint16_t anim_last;                  /* last step timestamp */
static uint16_t anim_phase;                 /* animation phase counter (also used as
                                              * SUNDOWN's elapsed-step counter) */
static uint16_t anim_total_steps;           /* SUNDOWN only: steps for a full fade */

static uint32_t rng_state = 0xA5A5F00D;
static inline uint32_t rng(void) {
    rng_state ^= rng_state << 13; rng_state ^= rng_state >> 17; rng_state ^= rng_state << 5;
    return rng_state;
}

/* Stop any running animation and clear all pending timed-off deadlines. Called
 * by every immediate command so manual control always wins. */
static void cancel_dynamic(void) {
    anim = 0;
    for (int i = 0; i < LED_COUNT; i++) led_timed[i] = 0;
}

/* NeoPixel-style colour wheel: hue 0..255 -> RGB. */
static void wheel(uint8_t pos, uint8_t *r, uint8_t *g, uint8_t *b) {
    if (pos < 85)       { *r = 255 - pos*3; *g = pos*3;       *b = 0; }
    else if (pos < 170) { pos -= 85;  *r = 0; *g = 255 - pos*3; *b = pos*3; }
    else                { pos -= 170; *r = pos*3; *g = 0;     *b = 255 - pos*3; }
}

static void anim_render(void) {
    switch (anim) {
        case 1: /* rainbow rotate */
            for (int i = 0; i < LED_COUNT; i++)
                wheel((uint8_t)(anim_phase + i * (256 / LED_COUNT)), &fr[i], &fg[i], &fb[i]);
            anim_phase += 4;
            break;
        case 2: { /* breathe (triangle on base colour) */
            uint8_t t = anim_phase & 0xFF;
            uint8_t lvl = (t < 128) ? (uint8_t)(t * 2) : (uint8_t)((255 - t) * 2);
            for (int i = 0; i < LED_COUNT; i++) {
                fr[i] = (uint16_t)anim_r * lvl / 255;
                fg[i] = (uint16_t)anim_g * lvl / 255;
                fb[i] = (uint16_t)anim_b * lvl / 255;
            }
            anim_phase += 4;
            break;
        }
        case 3: /* theatre chase (every 3rd LED, base colour) */
            for (int i = 0; i < LED_COUNT; i++) {
                uint8_t on = (((i + anim_phase) % 3) == 0);
                fr[i] = on ? anim_r : 0; fg[i] = on ? anim_g : 0; fb[i] = on ? anim_b : 0;
            }
            anim_phase += 1;
            break;
        case 4: { /* colour wipe (fill up then clear, repeat) */
            uint8_t k = anim_phase % (LED_COUNT + 1);
            for (int i = 0; i < LED_COUNT; i++) {
                uint8_t on = (i < k);
                fr[i] = on ? anim_r : 0; fg[i] = on ? anim_g : 0; fb[i] = on ? anim_b : 0;
            }
            anim_phase += 1;
            break;
        }
        case 5: /* twinkle (random sparkle in base colour) */
            for (int i = 0; i < LED_COUNT; i++) {
                if ((rng() & 0x07) == 0) { fr[i] = anim_r; fg[i] = anim_g; fb[i] = anim_b; }
                else                     { fr[i] = 0; fg[i] = 0; fb[i] = 0; }
            }
            anim_phase += 1;
            break;
        case 6: { /* SUNDOWN: one-shot fade from full brightness to off over
                   * anim_total_steps steps, EASED (quadratic ease-out: fast
                   * dim at the start, slow crawl to zero at the end) - see the
                   * SUNDOWN comment block above anim_render() for the formula
                   * and why speed means "minutes" here, not "ms/step". */
            uint16_t t = anim_phase;                       /* elapsed steps */
            if (t >= anim_total_steps) {
                set_all(0, 0, 0);
                anim = 0;                                   /* one-shot: stop, stay off */
                break;
            }
            /* frac = (1 - t/total)^2, computed in Q10 fixed point (0..1024).
             * remain10 = (1 - t/total) scaled to 0..1024 (16x16->32 bit, no FPU). */
            uint32_t remain10 = ((uint32_t)(anim_total_steps - t) << 10) / anim_total_steps;
            uint32_t frac10   = (remain10 * remain10) >> 10;  /* square, rescale back to Q10 */
            for (int i = 0; i < LED_COUNT; i++) {
                fr[i] = (uint8_t)(((uint32_t)anim_r * frac10) >> 10);
                fg[i] = (uint8_t)(((uint32_t)anim_g * frac10) >> 10);
                fb[i] = (uint8_t)(((uint32_t)anim_b * frac10) >> 10);
            }
            anim_phase += 1;
            break;
        }
        default: return;
    }
    show();
}

/* ============================================================
 * Command parser
 * ============================================================ */
typedef enum { PARSE_IDLE, PARSE_WAIT } ParseState;
static ParseState ps = PARSE_IDLE;
static uint8_t cmd_byte=0, cmd_buf[24], cmd_need=0, cmd_got=0;

/* ------------------------------------------------------------
 * 0xB0 ENTER_BOOTLOADER - hand off to the noknok USB bootloader for OTA.
 * Writes the agreed magic to the no-init handoff cell (top 16 B of RAM, kept
 * out of the linker's RAM region by app.ld so it survives a warm reset), then
 * a system reset. The bootloader runs first on every reset, sees the magic,
 * and stays in USB flashing mode. Same proven pattern as the I2C modules, and
 * NVIC_SystemReset is the reset we validated reboots cleanly on this chip.
 * NOTE: this app must be built with app.ld (linked at 0x2000 + handoff cell).
 * ------------------------------------------------------------ */
#define HANDOFF_CELL    (*(volatile uint32_t *)0x200027F0u)
#define ENTER_BL_MAGIC  0x6E6B4F54u   /* 'nkOT' - must match the bootloader */

static void enter_bootloader(void) {
    HANDOFF_CELL = ENTER_BL_MAGIC;
    NVIC_SystemReset();
    while (1) { }   /* unreachable */
}

static void execute(void) {
    switch (cmd_byte) {
        case 0x00: cancel_dynamic(); set_all(0,0,0); show(); break;
        case 0x01: cancel_dynamic(); set_all(cmd_buf[0],cmd_buf[1],cmd_buf[2]); show(); break;
        case 0x02:
            cancel_dynamic();
            if (cmd_buf[0] < LED_COUNT) {
                fr[cmd_buf[0]]=cmd_buf[1]; fg[cmd_buf[0]]=cmd_buf[2]; fb[cmd_buf[0]]=cmd_buf[3]; show();
            }
            break;
        case 0x03: brightness = cmd_buf[0]; show(); break;
        case 0x04:
            cancel_dynamic();
            for (int i=0;i<LED_COUNT;i++){ fr[i]=cmd_buf[i*3+0]; fg[i]=cmd_buf[i*3+1]; fb[i]=cmd_buf[i*3+2]; }
            show(); break;
        case 0x05: show(); break;

        case 0x10: { /* SET_LED: i R G B brightness durLo durHi */
            cancel_dynamic();
            uint8_t idx = cmd_buf[0], r = cmd_buf[1], g = cmd_buf[2], b = cmd_buf[3];
            brightness = cmd_buf[4];
            uint16_t dur = (uint16_t)cmd_buf[5] | ((uint16_t)cmd_buf[6] << 8);
            uint16_t deadline = now_ms() + dur;
            if (idx == 0xFF) {
                set_all(r, g, b);
                if (dur) for (int i=0;i<LED_COUNT;i++){ led_deadline[i]=deadline; led_timed[i]=1; }
            } else if (idx < LED_COUNT) {
                fr[idx]=r; fg[idx]=g; fb[idx]=b;
                if (dur) { led_deadline[idx]=deadline; led_timed[idx]=1; }
            }
            show();
            break;
        }
        case 0x20: { /* PLAY_PRESET: preset speed R G B */
            uint8_t p = cmd_buf[0];
            if (p >= 1 && p <= 6) {
                for (int i=0;i<LED_COUNT;i++) led_timed[i]=0;  /* drop pending timed-offs */
                anim = p;
                anim_r = cmd_buf[2]; anim_g = cmd_buf[3]; anim_b = cmd_buf[4];
                anim_phase = 0;
                if (p == 6) {
                    /* SUNDOWN reinterprets `speed` as MINUTES (not ms/step) -
                     * a 1-byte ms/step can't encode a 30-minute total duration.
                     * speed=0 -> default 30 min. Fixed cadence: 1 render/second
                     * (smooth enough for a slow fade, keeps anim_total_steps
                     * within a uint16_t for up to ~18 hours). */
                    uint8_t minutes = cmd_buf[1] ? cmd_buf[1] : 30;
                    anim_step_ms = 1000;
                    anim_total_steps = (uint16_t)((uint32_t)minutes * 60u);
                } else {
                    anim_step_ms = cmd_buf[1] ? cmd_buf[1] : 40;
                }
                anim_last = now_ms();
                anim_render();   /* draw first frame immediately */
            }
            break;
        }

        case 0xF0: { static const uint8_t id[3]={0x4E,0x4E,0x04}; USBD_SendEndpoint(3, (uint8_t*)id, 3); break; }
        case 0xB1: { static const uint8_t ver[4]={PROTOCOL_VERSION,FW_VERSION_MAJOR,FW_VERSION_MINOR,FW_VERSION_PATCH}; USBD_SendEndpoint(3, (uint8_t*)ver, 4); break; }
        case 0xB0: enter_bootloader(); break;  /* ENTER_BOOTLOADER (no reply; resets) */
    }
}

static void process_byte(uint8_t b) {
    if (ps == PARSE_IDLE) {
        cmd_byte = b; cmd_got = 0;
        switch (b) {
            case 0x00: cmd_need=0; break;
            case 0x01: cmd_need=3; break;
            case 0x02: cmd_need=4; break;
            case 0x03: cmd_need=1; break;
            case 0x04: cmd_need=24; break;
            case 0x05: cmd_need=0; break;
            case 0x10: cmd_need=7; break;
            case 0x20: cmd_need=5; break;
            case 0xF0: cmd_need=0; break;
            case 0xB1: cmd_need=0; break;
            case 0xB0: cmd_need=0; break;
            default: return;
        }
        if (cmd_need==0) execute(); else ps=PARSE_WAIT;
    } else {
        cmd_buf[cmd_got++] = b;
        if (cmd_got >= cmd_need) { execute(); ps=PARSE_IDLE; }
    }
}
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
int main(void) {
    clock_to_hse_48();        /* crystal-accurate 48 MHz first */
    build_serial();           /* fill iSerialNumber from chip UID before enumeration */
    USBDSetup();              /* FSDEV USB device (asserts EXTEN_USBD_PU_EN) */
    timebase_init();          /* TIM3 1 ms tick */
    ws_init();                /* re-enables DMA1 after USBDSetup AHBPCENR overwrite */

    /* Boot flash: dim white 300 ms */
    set_all(20,20,20); show();
    Delay_Ms(300);
    set_all(0,0,0); show();

    while (1) {
        rx_poll();            /* parse everything received over USB since last pass */

        uint16_t t = now_ms();

        /* Service per-LED timed-off deadlines (0x10 duration). */
        uint8_t need_show = 0;
        for (int i = 0; i < LED_COUNT; i++) {
            if (led_timed[i] && (int16_t)(t - led_deadline[i]) >= 0) {
                fr[i] = fg[i] = fb[i] = 0; led_timed[i] = 0; need_show = 1;
            }
        }
        if (need_show) show();

        /* Service the active animation (0x20). */
        if (anim && (int16_t)(t - anim_last) >= (int16_t)anim_step_ms) {
            anim_last += anim_step_ms;
            anim_render();
        }

        Delay_Ms(1);
    }
}

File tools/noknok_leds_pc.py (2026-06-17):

#!/usr/bin/env python3
"""
noknok_leds_pc.py â€” drive the noknok LEDs module from a PC (Windows / macOS / Linux).

The module is a USB CDC device (VID 0x1209, PID 0x4E4E). It appears as a virtual
serial port; this library talks the binary LED protocol over it.

Install once:
    pip install pyserial

Library use:
    from noknok_leds_pc import NoknokLEDs
    leds = NoknokLEDs.find()          # auto-detect by VID/PID (or identity query)
    leds.set_all(255, 0, 0)           # all red
    leds.set_pixel(3, 0, 255, 0)      # LED 3 green
    leds.set_brightness(64)           # dim
    leds.off()
    leds.close()

    # or as a context manager:
    with NoknokLEDs.find() as leds:
        leds.fill(0x00FF80)

Command line:
    python noknok_leds_pc.py list                 # list candidate ports
    python noknok_leds_pc.py all 255 0 0          # all red
    python noknok_leds_pc.py pixel 3 0 255 0      # LED 3 green
    python noknok_leds_pc.py bright 64            # brightness
    python noknok_leds_pc.py off                  # all off
    python noknok_leds_pc.py rainbow              # rainbow demo (Ctrl-C to stop)
    python noknok_leds_pc.py demo                 # full self-test
    python noknok_leds_pc.py --port COM12 all 0 0 255   # force a specific port

Protocol (host -> device):
    0x00              all off
    0x01 R G B        set all 8 LEDs
    0x02 i R G B      set LED i (0-7)
    0x03 B            global brightness 0-255
    0x04 [24 bytes]   set all 8 LEDs: 8 x (R G B)
    0x05              explicit show
    0xF0              identity query -> device replies [0x4E, 0x4E, 0x04]
"""

import sys
import time

try:
    import serial
    import serial.tools.list_ports
except ImportError:
    sys.stderr.write("This tool needs pyserial.  Install it with:\n    pip install pyserial\n")
    raise

# â”€â”€ Module identity â”€â”€â”€â”€â”€â”€â”€â”€â”€â”€â”€â”€â”€â”€â”€â”€â”€â”€â”€â”€â”€â”€â”€â”€â”€â”€â”€â”€â”€â”€â”€â”€â”€â”€â”€â”€â”€â”€â”€â”€â”€â”€â”€â”€â”€â”€â”€â”€â”€â”€â”€â”€â”€â”€â”€â”€â”€â”€â”€â”€
USB_VID      = 0x1209
USB_PID      = 0x4E4E
LED_COUNT    = 8
MODULE_TYPE  = 0x04
IDENTITY     = bytes([0x4E, 0x4E, MODULE_TYPE])   # reply to the 0xF0 query


def _c(v: int) -> int:
    """Clamp to a 0-255 byte."""
    return 0 if v < 0 else 255 if v > 255 else int(v)


class NoknokLEDsError(RuntimeError):
    pass


class NoknokLEDs:
    """Driver for the noknok LEDs module over its USB CDC serial port."""

    LED_COUNT = LED_COUNT

    # â”€â”€ Construction / discovery â”€â”€â”€â”€â”€â”€â”€â”€â”€â”€â”€â”€â”€â”€â”€â”€â”€â”€â”€â”€â”€â”€â”€â”€â”€â”€â”€â”€â”€â”€â”€â”€â”€â”€â”€â”€â”€â”€â”€â”€â”€â”€â”€â”€
    def __init__(self, port: str, *, verify: bool = True, timeout: float = 0.5):
        """
        Open the module on a known port, e.g.:
            NoknokLEDs("COM12")              # Windows
            NoknokLEDs("/dev/ttyACM0")       # Linux
            NoknokLEDs("/dev/cu.usbmodemXX") # macOS
        Set verify=False to skip the identity handshake.
        """
        self.port = port
        self._ser = serial.Serial(port, baudrate=115200, timeout=timeout, write_timeout=2)
        time.sleep(0.1)  # let the CDC settle after open
        if verify and not self.identify():
            self._ser.close()
            raise NoknokLEDsError(f"{port} did not respond as a noknok LEDs module")

    @classmethod
    def find(cls, *, timeout_sec: float = 5.0) -> "NoknokLEDs":
        """
        Auto-detect the module. First tries ports matching VID/PID; if none match
        (some OSes don't expose VID/PID on CDC), falls back to probing every port
        with the 0xF0 identity query. Returns a connected instance or raises.
        """
        deadline = time.monotonic() + timeout_sec
        while time.monotonic() < deadline:
            ports = list(serial.tools.list_ports.comports())
            # Pass 1: VID/PID match (fast, reliable on Windows/Linux)
            for p in ports:
                if (p.vid, p.pid) == (USB_VID, USB_PID):
                    try:
                        return cls(p.device, verify=True)
                    except (serial.SerialException, OSError, NoknokLEDsError):
                        pass
            # Pass 2: identity probe on the rest
            for p in ports:
                if (p.vid, p.pid) == (USB_VID, USB_PID):
                    continue
                try:
                    return cls(p.device, verify=True)
                except (serial.SerialException, OSError, NoknokLEDsError):
                    pass
            time.sleep(0.2)
        raise NoknokLEDsError("noknok LEDs module not found - is it plugged in?")

    @staticmethod
    def list_ports():
        """Return a list of (device, description, vid, pid) for all serial ports."""
        return [(p.device, p.description, p.vid, p.pid)
                for p in serial.tools.list_ports.comports()]

    # â”€â”€ Core commands â”€â”€â”€â”€â”€â”€â”€â”€â”€â”€â”€â”€â”€â”€â”€â”€â”€â”€â”€â”€â”€â”€â”€â”€â”€â”€â”€â”€â”€â”€â”€â”€â”€â”€â”€â”€â”€â”€â”€â”€â”€â”€â”€â”€â”€â”€â”€â”€â”€â”€â”€â”€â”€â”€â”€
    def off(self):
        """Turn all LEDs off."""
        self._send(bytes([0x00]))

    def set_all(self, r: int, g: int, b: int):
        """Set all 8 LEDs to one colour (R, G, B each 0-255)."""
        self._send(bytes([0x01, _c(r), _c(g), _c(b)]))

    def set_pixel(self, index: int, r: int, g: int, b: int):
        """Set a single LED (0-7) to a colour."""
        if not 0 <= index < LED_COUNT:
            raise ValueError(f"LED index must be 0-{LED_COUNT - 1}")
        self._send(bytes([0x02, index, _c(r), _c(g), _c(b)]))

    def set_brightness(self, brightness: int):
        """Global brightness 0-255, applied on top of the per-LED colours."""
        self._send(bytes([0x03, _c(brightness)]))

    def set_pixels(self, pixels):
        """
        Set all 8 LEDs at once. `pixels` is an iterable of up to 8 (r, g, b)
        tuples; any missing LEDs are turned off.
        """
        data = bytearray([0x04])
        for r, g, b in list(pixels)[:LED_COUNT]:
            data += bytes([_c(r), _c(g), _c(b)])
        while len(data) < 1 + LED_COUNT * 3:
            data += b"\x00\x00\x00"
        self._send(bytes(data))

    def fill(self, hex_color: int):
        """Set all LEDs to a 24-bit hex colour, e.g. fill(0xFF8000)."""
        self.set_all((hex_color >> 16) & 0xFF, (hex_color >> 8) & 0xFF, hex_color & 0xFF)

    def show(self):
        """Explicit show (setters already auto-show; here for completeness)."""
        self._send(bytes([0x05]))

    def identify(self) -> bool:
        """Send 0xF0 and check for the [0x4E,0x4E,0x04] identity reply."""
        try:
            self._ser.reset_input_buffer()
            self._send(bytes([0xF0]))
            return self._ser.read(3) == IDENTITY
        except (serial.SerialException, OSError):
            return False
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

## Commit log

2026-05-08 Create hardware/kicad folder
2026-06-01 Update product name to # noknok LEDs
2026-06-02 Fix ws_show: replace ISR with polling (DMA TC flag)
    [noknok_leds.c]
2026-06-02 Fix USB: use 144MHz HSI (fsusb requires 144/96/48MHz), fix WS2812b timing
    [noknok_leds.c]
2026-06-02 Fix: enable AFIO clock (PA3 AF), add SWEVGR trigger, remove boot flash for USB test
    [noknok_leds.c]
2026-06-02 firmware: v1.1 - interrupt DMA, 144 MHz, AFIO fix, boot flash
    [noknok_leds.c]
2026-06-04 firmware v1.4: switch to USBD/FSDEV + manual HSE clock - USB now enumerates
2026-06-04 firmware v1.4: USBD CDC descriptors (VID 1209/PID 4E4E)
2026-06-04 tools: add led_test.ps1 (raw-handle COM test - works around PowerShell SerialPort)
2026-06-04 tools: rewrite noknok_leds_pc.py - full PC driver (auto-detect, API, animations, CLI)
2026-06-04 tools: add noknok_leds.ps1 - PowerShell driver (raw handle, auto-detect, verified working)
2026-06-17 tools: add 'version' and 'id' commands to PowerShell driver (reads 0xB1/0xF0 reply)
2026-06-17 tools: add version() method + 'version' CLI to Python driver (0xB1)
2026-06-18 Firmware v1.6: unique USB serial + rich LED control & presets
    - Unique iSerialNumber built at boot from the CH32V203 96-bit chip UID
    (ESIG 0x1FFFF7E8) -> 24 hex chars, so each module is uniquely identifiable
    on the USB bus (USB counterpart of the I2C UID). Replaces hardcoded "007".
    - 0x10 SET_LED: full per-LED control in one command (index/RGB/brightness/
    duration ms, non-blocking auto-off).
    - 0x20 PLAY_PRESET: 5 non-blocking animations (rainbow/breathe/chase/wipe/
    twinkle), fire-and-forget, mirroring the buzzer's preset tunes.
    - TIM3 free-running 1 ms timebase for durations + animation stepping.
    - Built clean on ch32fun (-Wall): FLASH 6052 B (18%), RAM 1056 B.
    - Updates firmware/rea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
    [noknok_leds.c]
2026-06-23 v1.8.0: bootloader-hosted app for USB OTA
    Relink the LED app to run under the noknok USB bootloader (module-USB-bootloader):
    - app.ld: link at 0x2000, reserve the top 16 B of RAM as the handoff cell
    - Makefile: LINKER_SCRIPT := app.ld
    - 0xB0 ENTER_BOOTLOADER now writes the handoff magic (0x6E6B4F54 @ 0x200027F0)
    + NVIC_SystemReset() so the bootloader catches it and stays in USB flash mode
    (replaces the abandoned factory-ROM-bootloader entry experiments)
    - firmware/bin/noknok_leds.bin = relinked v1.8.0 image (the OTA target)
    Validated: OTA-installed over USB via the bootloader; full app->bootloader->app
    round-trip with no jumper.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
    [noknok_leds.c]
2026-06-23 chore: remove redundant hardware/kicad/.keep (folder now has content)
2026-07-09 mechanical: add housing.json (noknok-housing/1) for the USB LEDs module
    40x40, clearance_top 1.6 (WS2812b), clearance_bottom 9 (8.5 mm header). USB-C on W,
    JST-SH on E; J4 (vertical JST) + J2 (header) interior. Fully-open LED face (d36).
    Mounting holes = intended M2.5 standard; current board holes oversized (Christopher to fix).
2026-08-25 hardware: rev 2.0 round board with 16x SKC6812RGBW, add BOM and schematic PDF, drop stale renders
    [LED_Module_CH32V203.kicad_pcb, LED_Module_CH32V203.kicad_sch, module_USB-LED_BOM.xls]
2026-08-28 hardware: revert to the 8x WS2812b board - the 16x SK6812 rev2 design moves to module-usb-led-16x
    [LED_Module_CH32V203.kicad_pcb, LED_Module_CH32V203.kicad_sch, module_USB-LED_BOM.xls]
2026-09-01 README: add trademark attribution for Qwiic and STEMMA QT
    The marks were already used adjectivally to state connector
    compatibility, which is permitted referential use - this adds the
    attribution and an explicit non-affiliation line, and corrects the
    capitalisation of STEMMA QT (Adafruit writes it uppercase).
2026-09-11 Add firmware/index.json (current-firmware index)
    Declares the current firmware for this module in the same commit as the
    binary, so the version and the bytes cannot drift apart. Product manifests
    now carry only a floor (min); the brain reads this file to decide what to
    install, and requires_bootloader tells it when an image is NOT installable
    on the module in front of it.
    Spec: Ecosystem/software/firmware-index.md
    Registry: Ecosystem/software/modules.json
2026-09-12 index: drop requires_bootloader (USB, no stage-0 port yet; layout omitted per spec)
2026-09-29 fw 1.8.2: lossless USB receive (ring buffer + NAK flow control)
    ch32fun usbd.c's printf receive path (FUNCONF_USE_USBPRINTF) keeps a 64-byte
    buffer and discards the OLDEST bytes when another packet arrives before the
    main loop polls; the parser then desyncs and stray 0x00 bytes run as ALL OFF.
    Found on the LEDs 16x bench (same code, reproduced there from a Pi4).
    - USBPRINTF off (+ NULL_PRINTF); the app implements HandleDataOut /
    HandleInRequest / HandleSetupCustom: 256-byte ring filled in the USB IRQ,
    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
